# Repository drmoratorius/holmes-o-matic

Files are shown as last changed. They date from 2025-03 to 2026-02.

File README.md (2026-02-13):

# Dr. Moratorius' Holmes-O-Matic

This is a repository explaining how I built my Holmes-O-Matic and also provides 
all of the required files and information.
Please note that this is more a repository that can help you build your own
or adapt it and not a full tutorial.

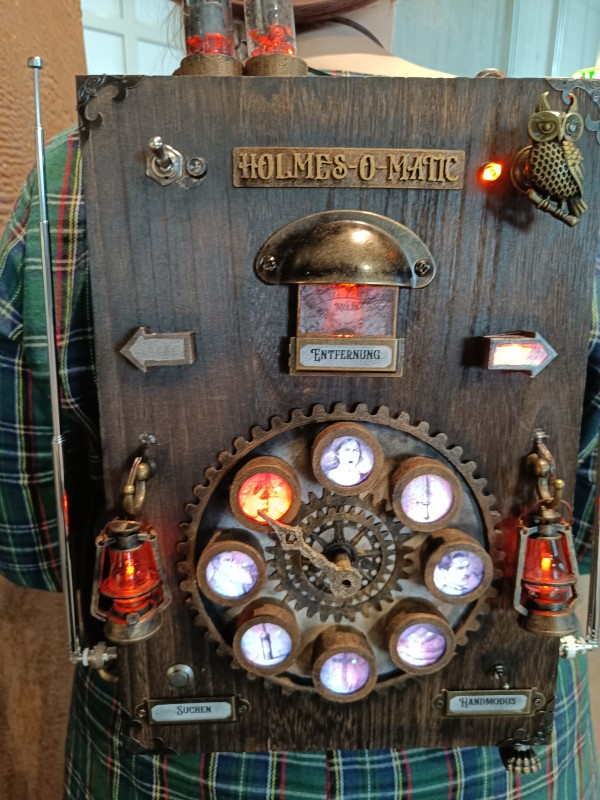
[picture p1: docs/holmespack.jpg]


## Features
* Powered by USB (power bank) connected to the ESP32 or via a DIY-18650 mini power bank.
* Powered by an ESP32 WROOM-32 using MicroPython
* Wooden Backpack

## Functionality
This project represents the Holmes-O-Matic, which is a Victorian-style device that detects crimes
nearby through the ether using the built-in antennas. When a crime is detected, the corresponding 
crime light will be illuminated and the hand will point on it and the distance from it will be shown on an illuminated analog meter. Also, the arrows will point into the direction of the crime.
There's also a manual mode that when enabled by the press of the button will illuminate all of the
lights in random colors for some time.
Please note that as this is a 180° servo not all 8 crimes will be reachable.

## Schematic
The project is comprised of three boards:

### 1. Main Board
Contains the ESP32 and connectivity to the other two boards and the WS2812B LEDs and the SG90 servo motor.
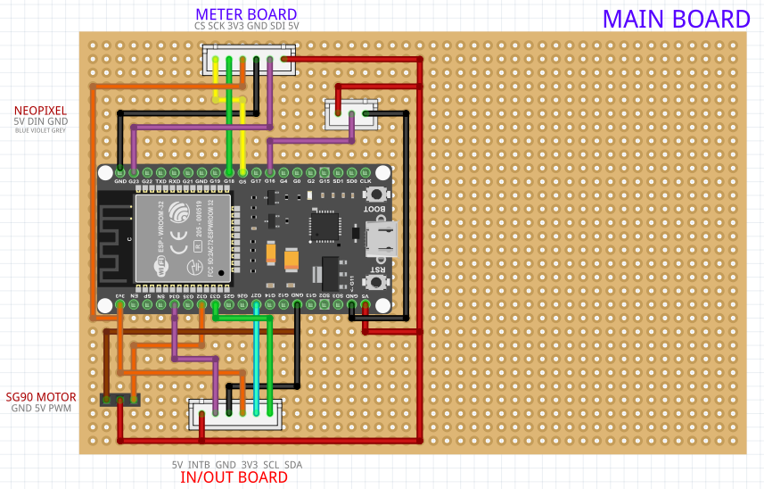
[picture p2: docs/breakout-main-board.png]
Main Board


### 2. Meter Board
The project includes a 5V voltmeter. This board therefore needs to run with 5V and is used to create a voltage between 0 and 5V. However, as the ESP32 utilized 3V3 GPIOs logic level converters are used.
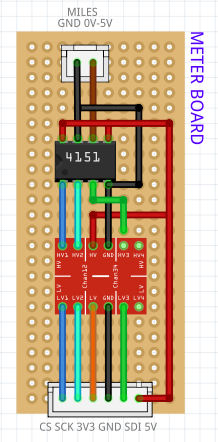
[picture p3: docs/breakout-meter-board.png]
Meter Board


### 3. In/Out Board
This port utilizes an MCP23017 and an ULN2803A and also a logic level converter again. This board therefore features potentially eight inputs (out of which two are used: one for the switch to manual mode
and one for the manual mode trigger button) and eight outputs four of which are used for dynamically controlling the lanterns, the meter illumination and the LED in the top right.
In/Out Board

### 4. Components
The SG90 servo motor and the diy WS2812B (neopixel) light strip are connected directly to the board.
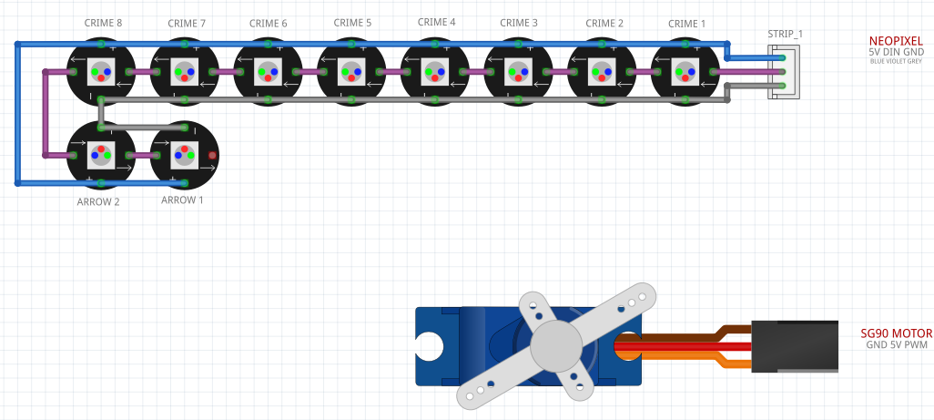
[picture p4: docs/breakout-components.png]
Components


## Components
* [parts list](docs/PARTS.MD)
* [labels (DOCX)](docs/Schilder.docx)
* [vial holder outer part pattern](docs/Schnittmuster.pdf) - print 100% (do not resize to printer edges) - does not fully cover outer part, but sufficient
* 3D printer files
  * [Large Cog Wheel - STL](3d/16cm_Cog_Wheel.stl) 
  * [Arrow - STL](3d/Arrow.stl)
  * [Navigator - STL](3d/Navigator.stl)
  * [Light Holder - STL](3d/Light_Holder.stl)
  * [Light Holder Cap - STL](3d/Light_Holder_Cap.stl)
  * [SG90 Hand - STL](3d/SG90_Hand.stl)
  * [SG90 Holder - STL](3d/SG90_Holder_Back.stl)
  * [Sign "Holmes-O-Matic" - STL](3d/sign_Holmes-O-Matic.stl)
  * [Tube Socket - STL](3d/Tube_Socket.stl)
* [Fritzing breadboard layout](fritzing/Moratorius-Holmes-O-Matic.fzz) - still missing schematic, tube lights not included (simply to flickering orange LEDs connected with 470R resistors to 5V and GND pins)

## Software
* The code uses the (latest MicroPython firmware for the ESP32)[https://micropython.org/download/ESP32_GENERIC/] and is flashed using (esptool.py)[https://docs.espressif.com/projects/esptool/en/latest/esp32/]
* The source code is available in the `src` directory
* Potential ideas for the future: allow control via smartphone through a WiFi AP

## Documents
You can find the printables for the signs and lights fully customizable in the (docs)[docs directory]. The crime images are all AI-generated and free to use.

## Pratical Notes
If you use a power bank please keep in mind that most turn off completely if the attached device
does not use a lot of power requiring you to open the case and turn on the powerbank again.

## Logo
* Font: Stone Board (LOGO) https://dirtylinestudio.com/product/stone-board/
* Font: Stanford Breath (Text) https://befonts.com/stanford-breath-font.html
* Font to STL: https://text2stl.mestres.fr/

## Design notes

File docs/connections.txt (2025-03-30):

IN/OUT BOARD - TOP:
- CS: GPIO 5
- SCK: GPIO 18
- 3V3: 3V3 (bottom)
- GND: GND
- SDI: GPIO 23
- 5V: 5V (bottom)

NEOPIXEL - TOP:
- BLUE: 5V
- VIOLET: GPIO 16
- GREY: GND (bottom)

SG90 MOTOR - BOTTOM:
- brown: GND (bottom)
- red: 5V 
- orange: GPIO 32

METER BOARD - BOTTOM:
- 5V
- INTB: GPIO 34
- GND
- 3V3
- SCL: GPIO 27
- SDA: GPIO 33

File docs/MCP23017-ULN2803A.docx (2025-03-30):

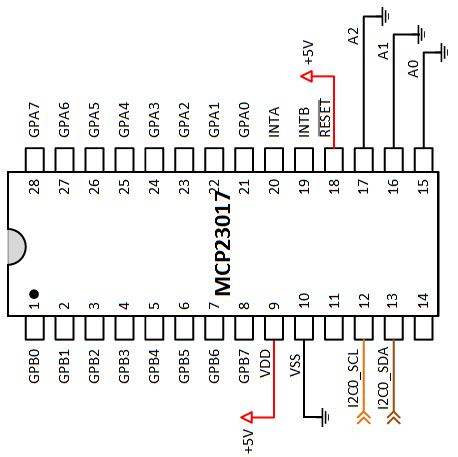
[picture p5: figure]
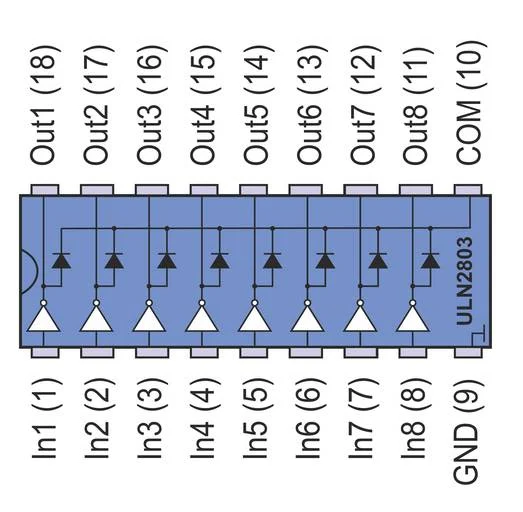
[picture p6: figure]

+5V

470 R

+5V

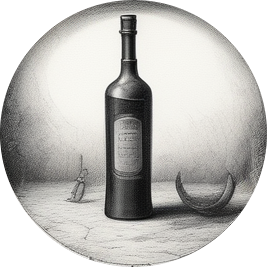
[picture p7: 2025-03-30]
docs/8 crime images/wine.png

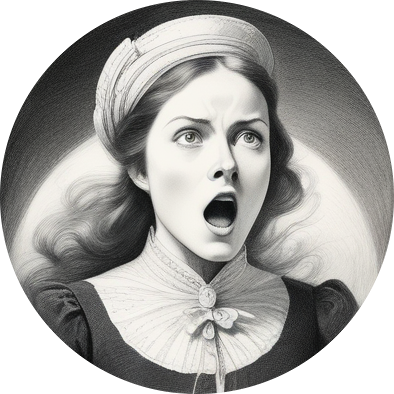
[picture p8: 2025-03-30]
docs/8 crime images/woman.png

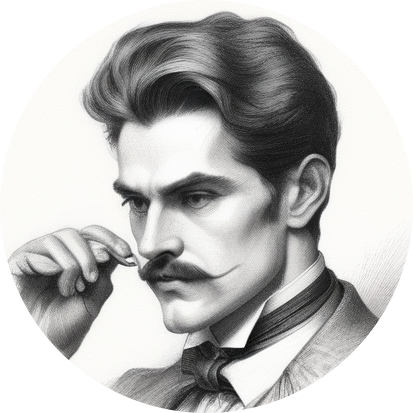
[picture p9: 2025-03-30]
docs/8 crime images/man.png

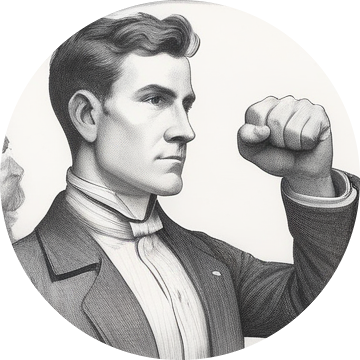
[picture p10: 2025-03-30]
docs/8 crime images/protest.png

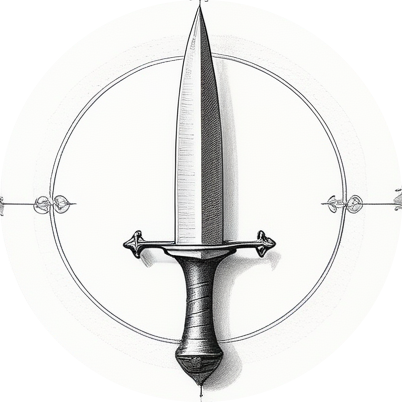
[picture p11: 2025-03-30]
docs/8 crime images/knife.png

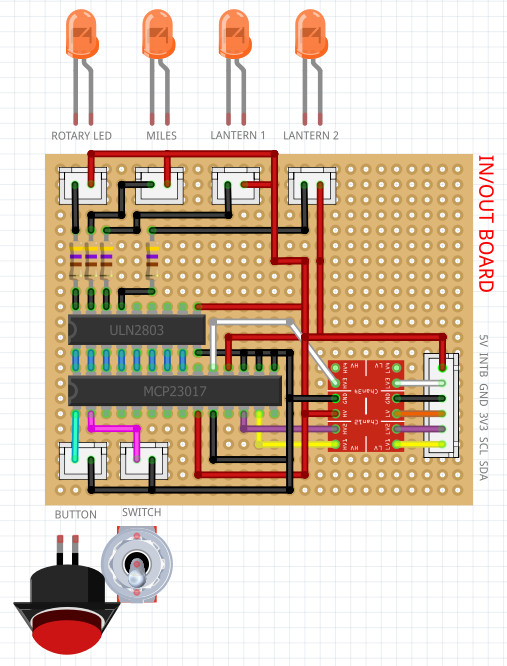
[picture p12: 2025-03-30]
docs/breakout-inout-board.png

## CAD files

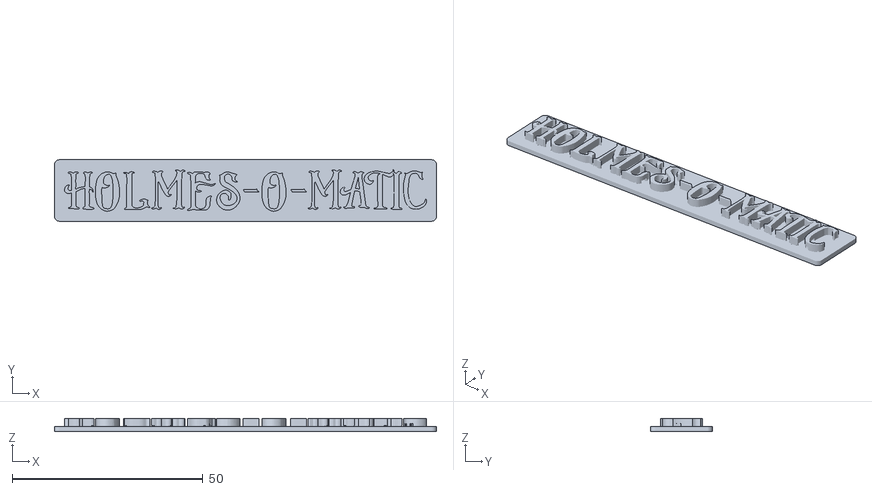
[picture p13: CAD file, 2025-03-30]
3d/Sign_Holmes-O-Matic.stl
100.2 x 16.1 x 3.38

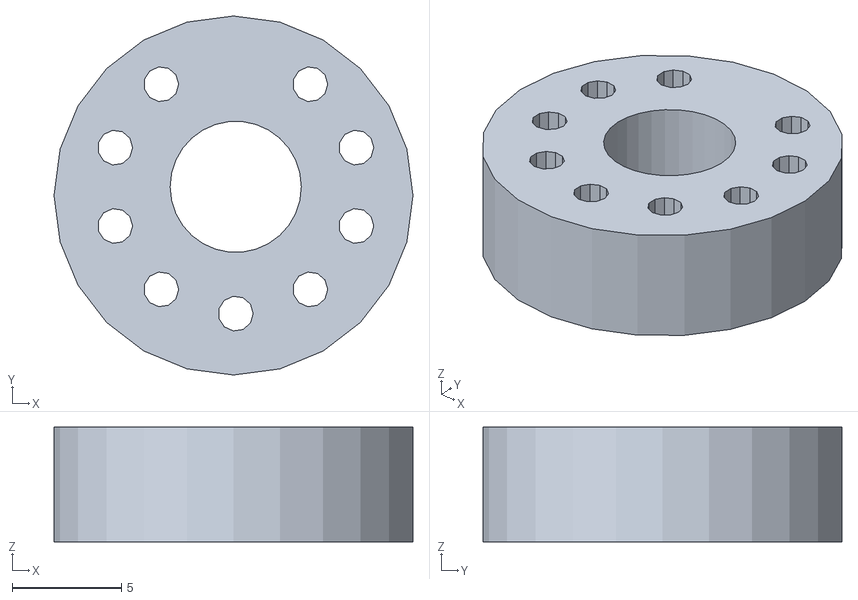
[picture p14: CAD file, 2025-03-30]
3d/Tube_Socket.stl
16.4 x 16.4 x 5.25

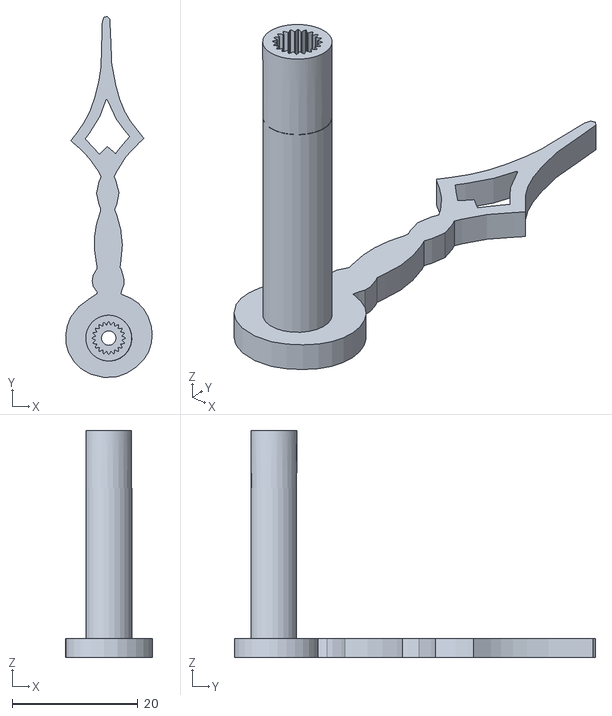
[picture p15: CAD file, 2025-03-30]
3d/SG90_Hand.stl
13.8 x 57.5 x 36.2

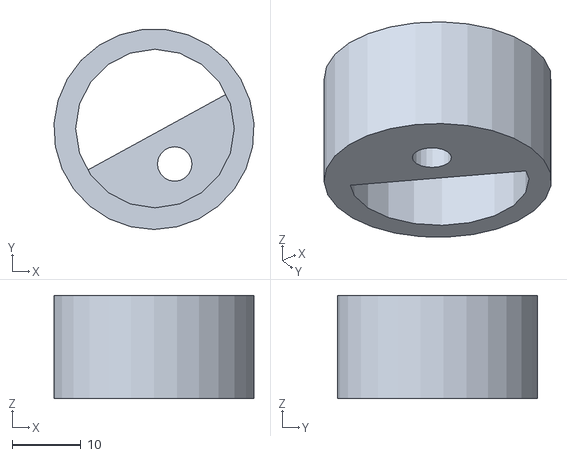
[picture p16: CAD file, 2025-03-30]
3d/Light_Holder.stl
29.0 x 29.0 x 15.0

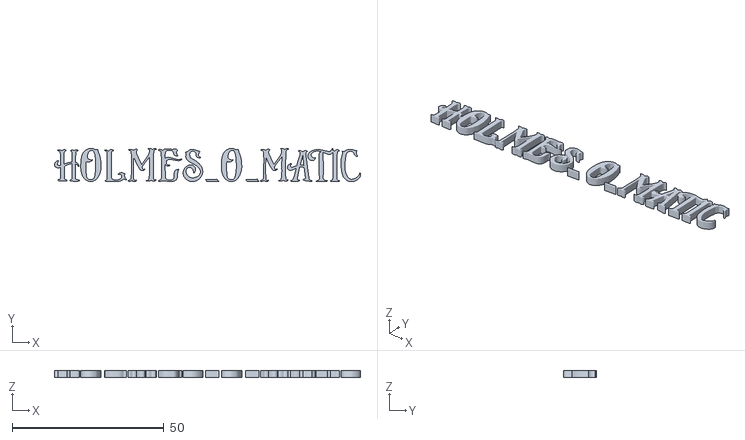
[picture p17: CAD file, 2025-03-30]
3d/Letters_Holmes-O-Matic.stl
100.8 x 11.0 x 2.21

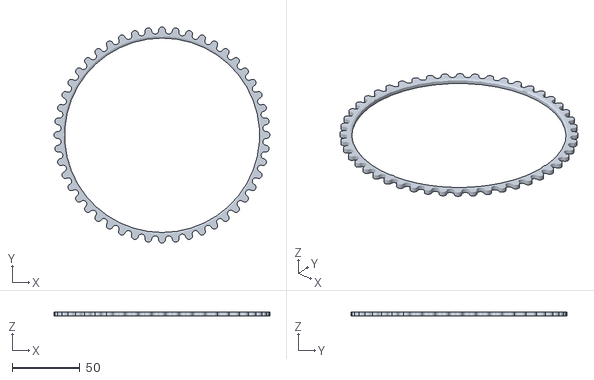
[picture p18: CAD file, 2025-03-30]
3d/16cm_Cog_Wheel.stl
160.0 x 160.0 x 3.00

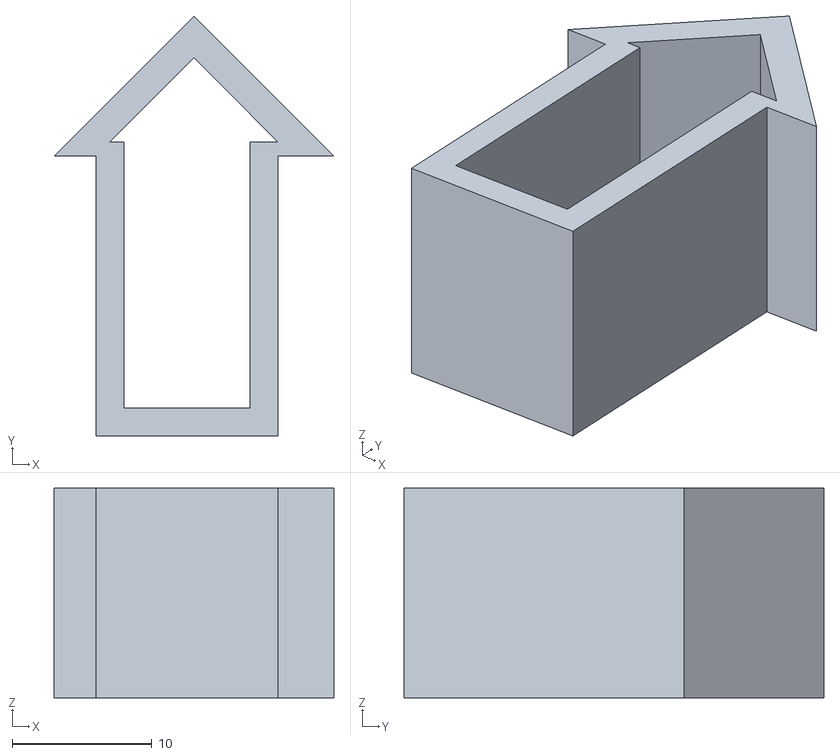
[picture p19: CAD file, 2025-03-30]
3d/Arrow.stl
20.0 x 30.0 x 15.0

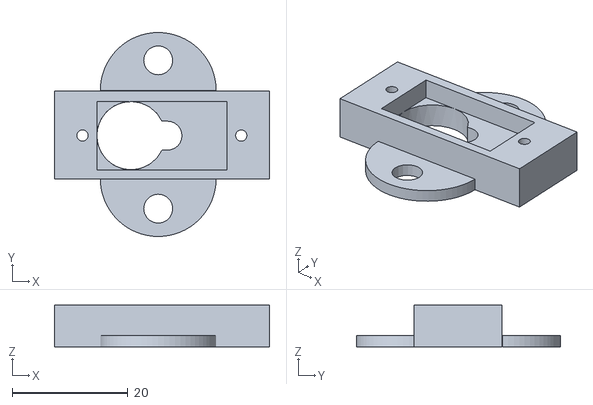
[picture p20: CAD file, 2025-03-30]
3d/SG90_Holder_Back.stl
37.1 x 35.2 x 7.20

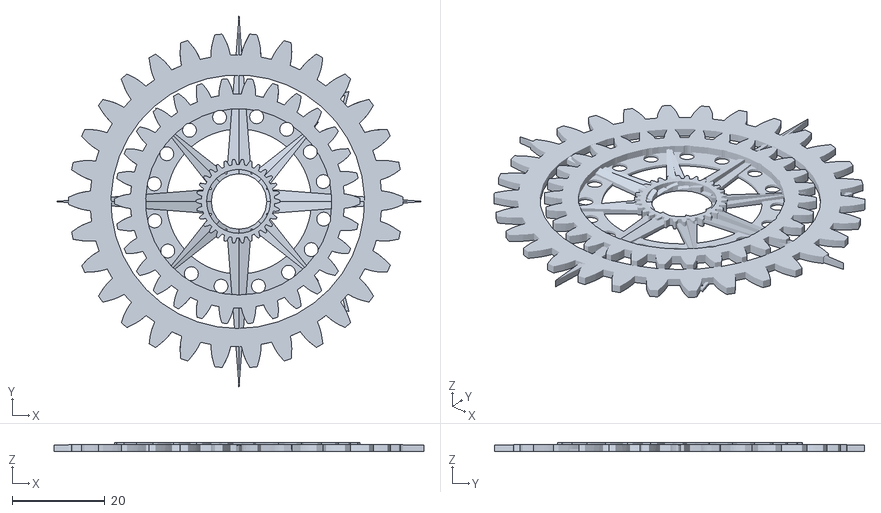
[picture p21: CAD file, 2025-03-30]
3d/Navigator.stl
80.0 x 80.0 x 1.99

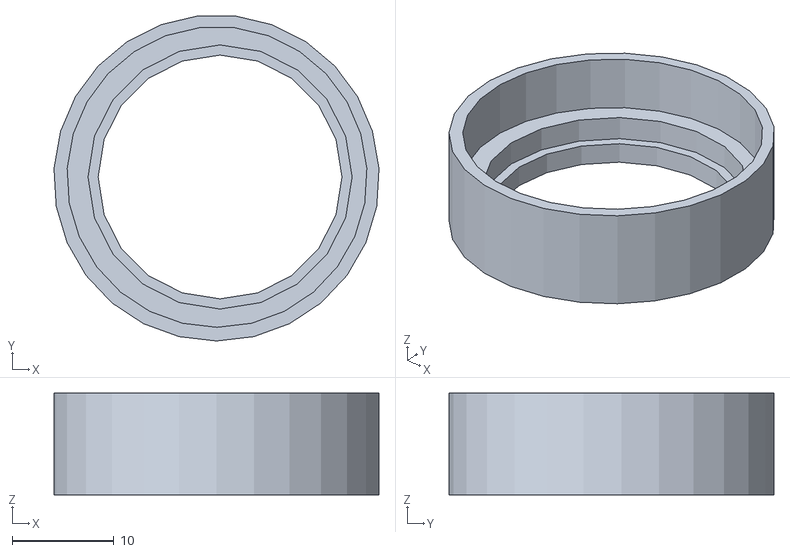
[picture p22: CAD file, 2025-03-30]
3d/Light_Holder_Cap.stl
32.0 x 32.0 x 10.0

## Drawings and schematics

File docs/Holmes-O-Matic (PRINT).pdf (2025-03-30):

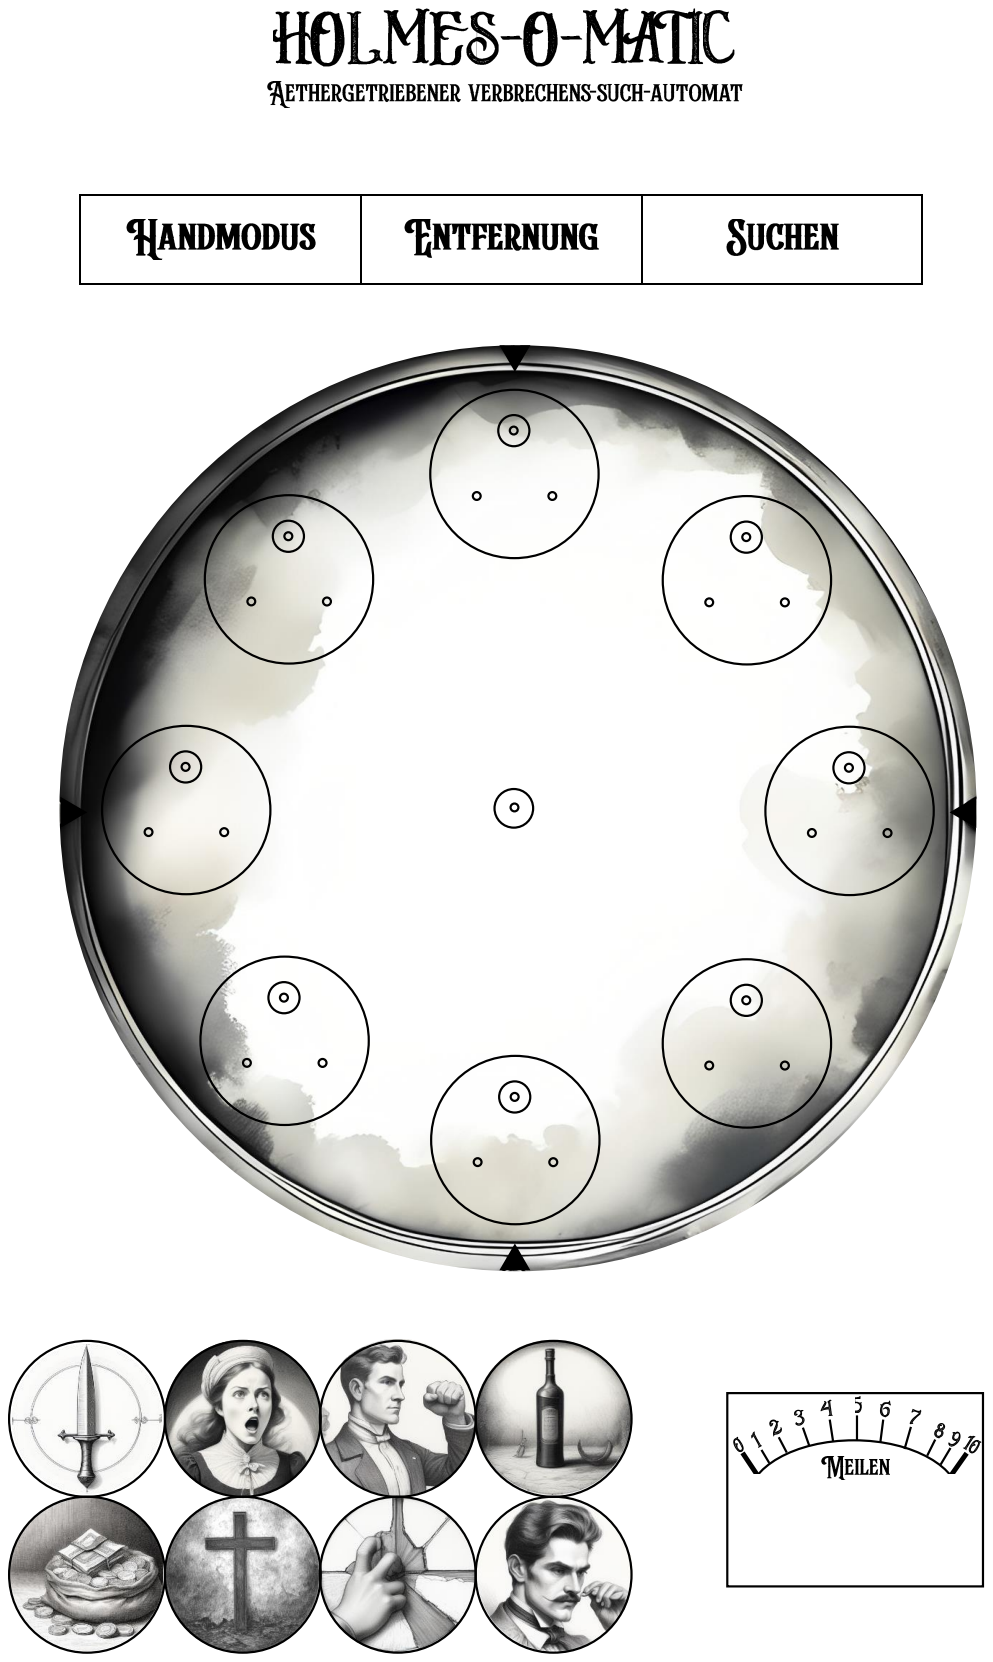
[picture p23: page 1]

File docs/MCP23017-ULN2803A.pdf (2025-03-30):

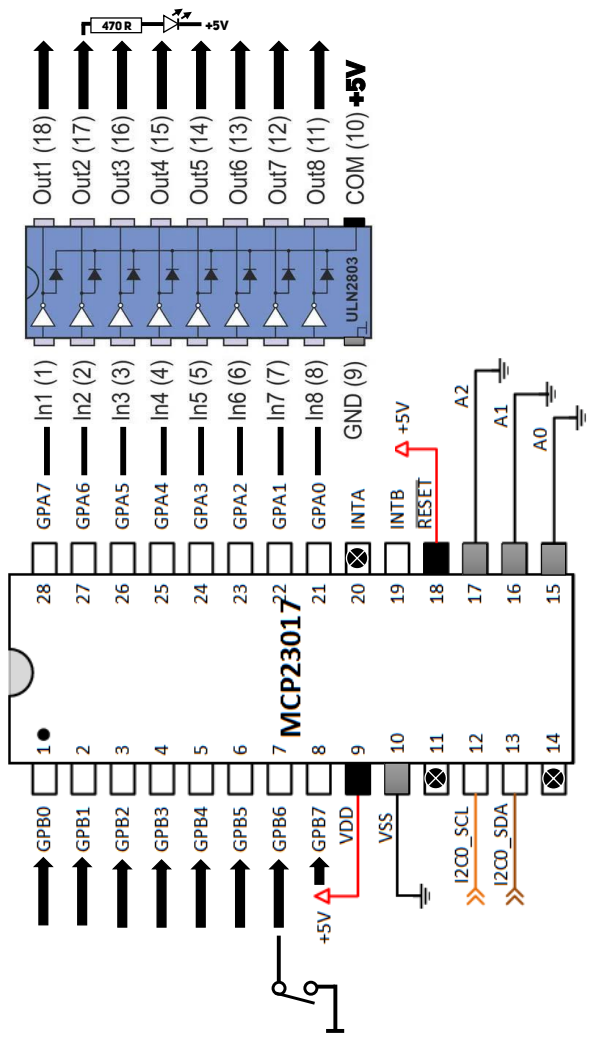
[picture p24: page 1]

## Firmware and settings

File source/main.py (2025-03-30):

import machine, neopixel, random
from machine import Pin, PWM
from time import sleep
import time
from morutils import *

#######################################################################################
######## C O N F I G U R A T I O N ####################################################
#######################################################################################

# SG90 MOTOR
motorGpio = 32
class Servo:
    def __init__(self, pin):
        self.pwm = PWM(Pin(pin), freq=50)
        self.min_duty = 26  # Duty for 0 degrees
        self.max_duty = 128  # Duty for 180 degrees

    def angle_to_duty(self, angle):
        return int(self.min_duty + (angle / 180.0) * (self.max_duty - self.min_duty))

    def move(self, angle):
        #self.start()
        duty = self.angle_to_duty(angle)
        self.pwm.duty(duty)
        
    def stop():
        self.pwm.deinit()

    def start():
        self.pwm.init()
        
servo = Servo(motorGpio)

# NEOPIXEL
neopixelGpio = 16
initialPixelColor = (0,0,0)
defaultPixelColor = (50, 50, 50)
activePixelColor = (240, 10, 0) #(255, 100, 0)
arrowPixelColor = (0, 255, 0)

# MCP 4151
potiSckPin = 18
potiMosiPin = 23
potiCsPin = 5

# MCP 23017
mcpAddr = 0x20
sdaPin=33
sclPin=27
MCP_IODIRA = 0x00  # Controls the direction of the data I/O for port A.
MCP_IODIRB = 0x01  # Controls the direction of the data I/O for port B.
MCP_IPOLA = 0x02  # Configures the polarity on the corresponding GPIO-port bits for port A.
MCP_IPOLB = 0x03  # Configures the polarity on the corresponding GPIO-port bits for port B.
MCP_GPINTENA = 0x04  # Controls the interrupt-on-change for each pin of port A.
MCP_GPINTENB = 0x05  # Controls the interrupt-on-change for each pin of port B.
MCP_DEFVALA = 0x06  # Controls the default comparison value for interrupt-on-change for port A.
MCP_DEFVALB = 0x07  # Controls the default comparison value for interrupt-on-change for port B.
MCP_INTCONA = 0x08  # Controls how the associated pin value is compared for the interrupt-on-change for port A.
MCP_INTCONB = 0x09  # Controls how the associated pin value is compared for the interrupt-on-change for port B.
MCP_IOCON = 0x0A  # Controls the device.
MCP_GPPUA = 0x0C  # Controls the pull-up resistors for the port A pins.
MCP_GPPUB = 0x0D  # Controls the pull-up resistors for the port B pins.
MCP_INTFA = 0x0E  # Reflects the interrupt condition on the port A pins.
MCP_INTFB = 0x0F  # Reflects the interrupt condition on the port B pins.
MCP_INTCAPA = 0x10  # Captures the port A value at the time the interrupt occurred.
MCP_INTCAPB = 0x11  # Captures the port B value at the time the interrupt occurred.
MCP_GPIOA = 0x12  # Reflects the value on the port A.
MCP_GPIOB = 0x13  # Reflects the value on the port B.
MCP_OLATA = 0x14  # Provides access to the port A output latches.
MCP_OLATB = 0x15  # Provides access to the port B output latches.
mcpIrqPinNo=34

# General settings
debug = False
testProgram = False
    
crimes = [
    {
        "title": 'Harassment',
        "pixel": 0,
        "angleValue": 90
    },
    {
        "title": 'Act of Violence',
        "pixel": 1,
        "angleValue": 45
    },
    {
        "title": 'Wanted Person',
        "pixel": 2,
        "angleValue": 0
    },
#    {
#        "title": 'Theft',
#        "pixel": 3,
#        "angleValue": 2000000
#    },
#    {
#        "title": 'Homicide',
#        "pixel": 4,
#        "angleValue": 1500000 #TODO
#    },
#    {
#        "title": 'Drunkenness',
#        "pixel": 5,
#        "angleValue": 1500000 # TODO
#    },
    {
        "title": 'Protest',
        "pixel": 6,
        "angleValue": 180
    },
    {
        "title": 'Burglary',
        "pixel": 7,
        "angleValue": 135
    }
]

lastCrime = 0
prevBankAPins = []
curValues = []
inputNames = ["NC8","NC7","NC6", "NC5","NC4","NC3","BUTTON", "SWITCH"]
currentProgram = 'AUTO'
interrupt_occurred = False
manual_initialized = False

#######################################################################################
######## F U N C T I O N S ############################################################
#######################################################################################
def custom_sleep(duration):
    global interrupt_occurred
    start_time = time.ticks_ms()
    while time.ticks_ms() - start_time < duration * 1000:
        # Check for interrupt or exit condition here
        if interrupt_occurred:  # Replace with your actual condition
            interrupt_occurred = False
            break
        time.sleep_ms(10)  # Sleep for a short duration

def calculate_duty_ns(angle):
    if angle < 0:
        angle = 0
    elif angle > 180:
        angle = 180
    
    # Pulsdauer für 0° und 180° in ns
    min_duty_ns = 1_000_000  # 1 ms
    max_duty_ns = 2_000_000  # 2 ms
    
    # Pulsdauer pro Grad berechnen
    duty_ns_per_degree = (max_duty_ns - min_duty_ns) / 180
    
    # Pulsdauer für den gewünschten Winkel berechnen
    duty_ns = min_duty_ns + (angle * duty_ns_per_degree)
    
    return int(duty_ns)

def motor_on():
    if debug: print('(FUNC) motor_on()')
    pwm.init()
    
def motor_off():
    if debug: print('(FUNC) motor_off()')
    pwm.deinit()

def motor_set(val):
    if debug: print('(FUNC) motor_set('+str(val)+')')
    print('(FUNC) motor_set('+str(val)+')')
    #pwm.duty_ns(val)
    servo.move(val)

def set_pixel_color(no, color):
    if debug: print('(FUNC) set_pixel_color('+str(no)+', '+str(color[0])+','+str(color[1])+', '+str(color[2])+')')
    np[no] = color
    np.write()
    
def set_all_pixel_colors(color):
    if debug: print('(FUNC) set_all_pixel_colors('+str(color[0])+','+str(color[1])+', '+str(color[2])+')')
    for i in range(8): # 2 arrows
        set_pixel_color(i, color)
    
def reset_crime_wheel():
    if debug: print('(FUNC) reset_crime_wheel()')
    set_all_pixel_colors(initialPixelColor)
    motor_set(90)
    custom_sleep(1)
    motor_off()
    
def set_crime(no):
    if debug: print('(FUNC) set_crime('+str(no)+')')
    print('---> Setting crime to ' + crimes[no]['title']);
    set_all_pixel_colors(defaultPixelColor)
    set_pixel_color(crimes[no]['pixel'], activePixelColor)
    motor_set(crimes[no]['angleValue'])
    
def set_random_crime():
    global lastCrime
    if debug: print('(FUNC) set_random_crime()')
    set_pot_value(random.randint(0, 255)) # Simulate distance
    randomCrime = random.randint(0, len(crimes) - 1)
    while randomCrime == lastCrime:
        randomCrime = random.randint(0, len(crimes) - 1)
    set_crime(randomCrime)
    lastCrime = randomCrime
    
def change_arrow_status(no, newState, newColor = arrowPixelColor):
    if debug: print('(FUNC) change_arrow_status('+str(no)+', '+str(newState)+')')
    if no == 1:
        if newState == True:
            set_pixel_color(8, newColor)
        else:
            set_pixel_color(8, initialPixelColor)
    if no == 2:
        if newState == True:
            set_pixel_color(9, newColor)
        else:
            set_pixel_color(9, initialPixelColor)

def arrow_activity():
    colorOn = (100, 40, 0)
    colorOff = (100, 100, 100)
    colorDir = (240, 10, 0)
    
    for i in range(random.randint(3, 10)):
        change_arrow_status(1, True, colorOn)
        change_arrow_status(2, True, colorOn)
        custom_sleep(0.4)
        change_arrow_status(1, False)
        change_arrow_status(2, False)
        custom_sleep(0.4)
        
    arrowNo = random.randint(1, 2)
    change_arrow_status(arrowNo, True, colorDir)
    custom_sleep(0.3)

def random_crime_animation():
    motor_set(90)
    set_all_pixel_colors(defaultPixelColor)
    set_pot_value(0)
    arrow_activity()
    set_random_crime()
    
    if testProgram == True:
        custom_sleep(1)
    else:
        custom_sleep(random.randint(3, 25))
    
def debug_mode():
    set_all_pixel_colors((255, 0, 255))
    motor_set(90)
    
def set_pot_value(value):
    cs.value(0)
    spi.write(b'\x00')
    spi.write(value.to_bytes(1, 'big'))
    cs.value(1)

def random_color():
    return [random.randint(0, 255), random.randint(0, 255), random.randint(0, 255)]

# Always receives an array of values: [['SP1', True], ['SP2', False]]...
def input_callback(changes):
    global currentProgram, interrupt_occurred
    eventSource = changes[0][0]
    eventValue = changes[0][1]
    
    if eventSource == 'SWITCH':
        if eventValue == True:
            currentProgram = 'MANUAL'
            print('Switched to **MANUAL**')
            interrupt_occurred = True
        else:
            currentProgram = 'AUTO'
            print('Switched to **AUTO**')
            interrupt_occurred = True
            manual_initialized = False
            
    if eventSource == 'BUTTON' and eventValue == True:
        if currentProgram == 'MANUAL':
            manual_initialized = True
            print('Pressed button in manual mode!')
            set_pixel_color(0, [255, 0, 0])
            custom_sleep(0.5)
            set_pixel_color(1, [255, 0, 0])
            custom_sleep(0.5)
            set_pixel_color(2, [255, 0, 0])
            custom_sleep(0.5)
            set_pixel_color(3, [255, 0, 0])
            custom_sleep(0.5)
            set_pixel_color(4, [255, 0, 0])
            custom_sleep(0.5)
            set_pixel_color(5, [255, 0, 0])
            custom_sleep(0.5)
            set_pixel_color(6, [255, 0, 0])
            custom_sleep(0.5)
            set_pixel_color(7, [255, 0, 0])
            
            custom_sleep(1)
            set_all_pixel_colors([0,0,0])
            
            for j in range (20):
                for i in range(10): # 2 arrows
                    set_pixel_color(i, random_color())
                    custom_sleep(0.05)
             
            custom_sleep(2)
            set_all_pixel_colors([0,0,0])
            custom_sleep(1)
            change_arrow_status(1, True)
            change_arrow_status(2, True)
            set_all_pixel_colors([200, 50, 10])        
            manual_initialized = True            
            interrupt_occurred = True
    
def SP_mcpCallback(pin):
    global prevBankAPins
    changes = []
    curValues = UTIL_convertBinaryValue(i2c.readfrom_mem(mcpAddr, MCP_GPIOB, 1))
    changedOffsets = UTIL_compare_bool_arrays(prevBankAPins, curValues)
    if len(changedOffsets):
        for offset in changedOffsets:
            print('INPUT ' + inputNames[offset] + ' changed to ' + str(curValues[offset]))
            changes.append([inputNames[offset], curValues[offset]])
        prevBankAPins = curValues
    if len(changes):
        input_callback(changes)
        
#######################################################################################
######## P R O G R A M ################################################################
#######################################################################################
    
# MCP 4151 INIT (SPI)
cs = machine.Pin(potiCsPin, machine.Pin.OUT)
spi = machine.SPI(1, baudrate=1000000, polarity=0, phase=0, sck=machine.Pin(potiSckPin), mosi=machine.Pin(potiMosiPin))

# NEOPIXEL INIT
np = neopixel.NeoPixel(machine.Pin(neopixelGpio), 10) # + 2 arrows
set_all_pixel_colors([0,0,0])

# MCP 23017 INIT
i2c = machine.I2C(0, scl=machine.Pin(sclPin), sda=machine.Pin(sdaPin), )
i2cdevices = i2c.scan()
print('[.] Configuring MCP23017 for program...')
i2c.writeto_mem(mcpAddr, MCP_IODIRB, b'\xFF')  # Bank B -> all input
print('[.] Set Bank B to input')
i2c.writeto_mem(mcpAddr, MCP_GPPUB, b'\xFF')
print('[.] Set Bank B all pull-up resistors on')
i2c.writeto_mem(mcpAddr, MCP_GPINTENB, b'\xFF')
print('[.] Set Bank B IRQ mode')
i2c.writeto_mem(mcpAddr, MCP_IODIRA, b'\x00')  # Bank A -> all output
print('[.] Set Bank A to output')
i2c.writeto_mem(mcpAddr, MCP_GPIOA, b'\x00')
print('[.] Set Bank A all outputs to 0')
print('[*] Reading current value of bank B')
curValues = UTIL_convertBinaryValue(i2c.readfrom_mem(mcpAddr, MCP_GPIOB, 1))
prevBankAPins = curValues
mcpIrqPin = machine.Pin(mcpIrqPinNo, machine.Pin.IN)
mcpIrqPin.irq(trigger=machine.Pin.IRQ_FALLING | machine.Pin.IRQ_RISING, handler=SP_mcpCallback)


# Bootup sequence
i2c.writeto_mem(mcpAddr, MCP_GPIOA, b'\xFF')
i2c.writeto_mem(mcpAddr, MCP_GPIOA, bytearray([0b10000000]))
sleep(1)
i2c.writeto_mem(mcpAddr, MCP_GPIOA, bytearray([0b11000000]))
sleep(1)
i2c.writeto_mem(mcpAddr, MCP_GPIOA, bytearray([0b11110000]))
sleep(1)
i2c.writeto_mem(mcpAddr, MCP_GPIOA, bytearray([0b11111000]))
sleep(1)
i2c.writeto_mem(mcpAddr, MCP_GPIOA, bytearray([0b11111100]))
sleep(0.3)
i2c.writeto_mem(mcpAddr, MCP_GPIOA, bytearray([0b11111110]))
sleep(0.3)
i2c.writeto_mem(mcpAddr, MCP_GPIOA, bytearray([0b11111111]))

while True:
    if currentProgram == 'AUTO':
        random_crime_animation()
        custom_sleep(2)
    else:
        print('Manual')
        if manual_initialized == False:
            change_arrow_status(1, True)
            change_arrow_status(2, True)
            set_all_pixel_colors([200, 50, 10])        
            manual_initialized = True
        custom_sleep(1)
